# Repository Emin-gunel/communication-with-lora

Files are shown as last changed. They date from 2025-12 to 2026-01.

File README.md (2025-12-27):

# LoRa-Pico-BME280

Kısa açıklama  
Raspberry Pi Pico 2 W ve Ai-Thinker RA-01 (SX1278) kullanılarak, BME280 sensöründen alınan sıcaklık/nispi nem/basınç verilerinin LoRa P2P ile diğer bir Pico node'a gönderilip terminalde gösterilmesi amaçlanmıştır. Dengeli, sade ve doğrudan kullanılabilir bir proje yapısı sunar.

---

## İçindekiler
- [Açıklama](#açıklama)  
- [Özellikler](#özellikler)  
- [Donanım](#donanım)  
- [Yazılım Mimarisi](#yazılım-mimarisi)  
- [Haberleşme Parametreleri](#haberleşme-parametreleri)   
- [Çalıştırma / Seri Monitör](#çalıştırma--seri-monitör)  
- [Testler](#testler)  
- [Katkıda Bulunma](#katkıda-bulunma)  
- [İletişim](#iletişim)

---

## Açıklama
Bu proje iki Pico tabanlı node (verici ve alıcı) arasında LoRa P2P haberleşmesi ile sensör verisi aktarımı gerçekleştirir. Verici tarafında BME280 sensöründen okunup paketlenen veriler LoRa ile gönderilir; alıcı tarafı bu paketleri alıp seri (terminal) üzerinde gösterir.

## Özellikler
- Basit P2P LoRa iletişimi (verici ↔ alıcı)  
- BME280 ile sıcaklık, nem ve basınç okuma  
- Taşınabilir C++ tabanlı uygulama (Pico SDK ile C/C++)
  
## Donanım
- Raspberry Pi Pico 2 W (her iki node için)  
- BME280 sensörü (I2C) — verici tarafta  
- AI Thinker RA-01 (SX1278) LoRa modülü — her node için ayrı modül  
- Anten (uygun 433 MHz anten)  
- Güç kaynağı (USB güç)

## Yazılım Mimarisi
- Sensör okuma (BME280, I2C)  
- Veri paketleme (koşullu, küçük paket yapısı)  
- LoRa gönderim (SX1278 üzerinden SPI)  
- RX tarafında alma ve seri terminale yazma

C++ standardı: C++17 (proje C++ ile yazılmıştır).

## Haberleşme Parametreleri
- Frekans: 433 MHz  
- Spreading Factor: SF7  
- Bandwidth: 125 kHz  
- Coding Rate: 4/5  
- TX Gücü: 17 dBm

Bu parametreler LoRa link'i ve menzili doğrudan etkiler — gerekirse ayarlanabilir.

## Çalıştırma / Seri Monitör
- Seri hız: 115200 baud (varsayılan; proje içinde değiştirilebilir).  
- Terminal ile izleme örneği:

```bash
# Linux / macOS
picocom /dev/ttyUSB0 -b 115200
# veya
minicom -D /dev/ttyUSB0 -b 115200
```
Verici: sensör verilerini periyodik olarak paket gönderir.  
Alıcı: gelen paketları çözümler ve terminale yazdırır.

## Testler
- Projede otomatik test altyapısı yoksa, ilk testler manuel olacaktır: verici ve alıcıyı aynı ortamda çalıştırıp, sensör okuma ve paket alımını doğrulayın.  
- Bir sonraki adım: basit bir loopback testi ve menzil testi yapmaktır (farklı mesafeler/engeller altında paket kaybını kontrol edin).

## Katkıda Bulunma
1. Fork → branch oluştur (ör. feature/iyileme-adi)  
2. Değişiklik yap → test et → PR aç  
3. Küçük, odaklı PR'lar tercih edilir; büyük değişiklikler için önce issue açın.

## İletişim
- Sahip / Repo: https://github.com/Emin-gunel (güncellemek isterseniz gerçek repo linkinizi ekleyin)

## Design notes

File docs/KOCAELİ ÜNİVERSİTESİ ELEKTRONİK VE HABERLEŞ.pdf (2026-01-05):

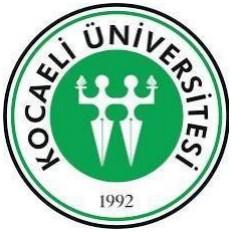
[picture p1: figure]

RASPBERRY Pİ PİCO 2W TABANLI LORA NOKTADAN NOKTAYA SENSÖR VERİ AKTARIMI SİSTEMİ

MÜHENDİSLİK TASARIM-1 DÖNEM PROJESİ Muhammet Emin GÜNEL 220208004

KOCAELİ ÜNİVERSİTESİ MÜHENDİSLİK FAKÜLTESİ Bölümü: Elektronik ve Haberleşme Mühendisliği Danışman: DOÇ. DR. ANIL ÇELEBİ

KOCAELİ, 2025

İÇİNDEKİLER

6.PROJEDE KULLANILAN YAZILIMLAR VE PROJE

### 1. GİRİŞ

Bu projede, Raspberry Pi Pico 2 W ve Ai-Thinker RA-01 LoRa modülleri kullanılarak iki nokta arasında kablosuz veri aktarımı gerşekleştirilmesi hedeflenmektedir. Verici tarafta BME280 sıcaklık–nem–basınç sensöründen alınan veriler LoRa P2P protokolü ile alıcı node’a aktarılmakta, alıcı bu veriyi terminalde göstermektedir. 2. PROJENİN AMACI

- Düşük güç tüketimli, uzun menzilli kablosuz haberleşme sistemi tasarlamak. ● LoRa P2P (Peer-to-Peer) haberleşmesini uygulamak. ● Sensör verisini güvenli şekilde iki cihaz arasında iletmek.

3.SİSTEM MİMARİSİ
3.1.Donanım Bileşenleri
- Raspberry Pi Pico 2W
- BME280 Sensörü
- AI Thinker RA-01(SX1278)
- Anten
- Güç Beslemesi

Sistem, bir verici (TX) ve bir alıcı (RX) düğümden oluşmaktadır. Verici düğümde BME280 sensörü kullanılarak çevresel veriler ölçülmüş, bu veriler mikrodenetleyici tarafından işlenerek LoRa modülü üzerinden kablosuz olarak iletilmiştir.

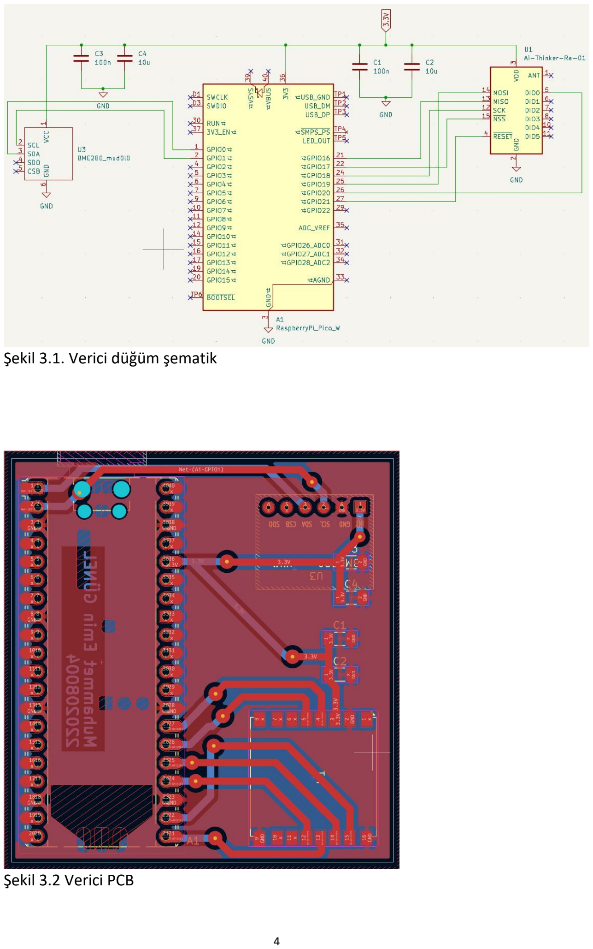
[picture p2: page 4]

Şekil 3.1. Verici düğüm şematik

Şekil 3.2 Verici PCB

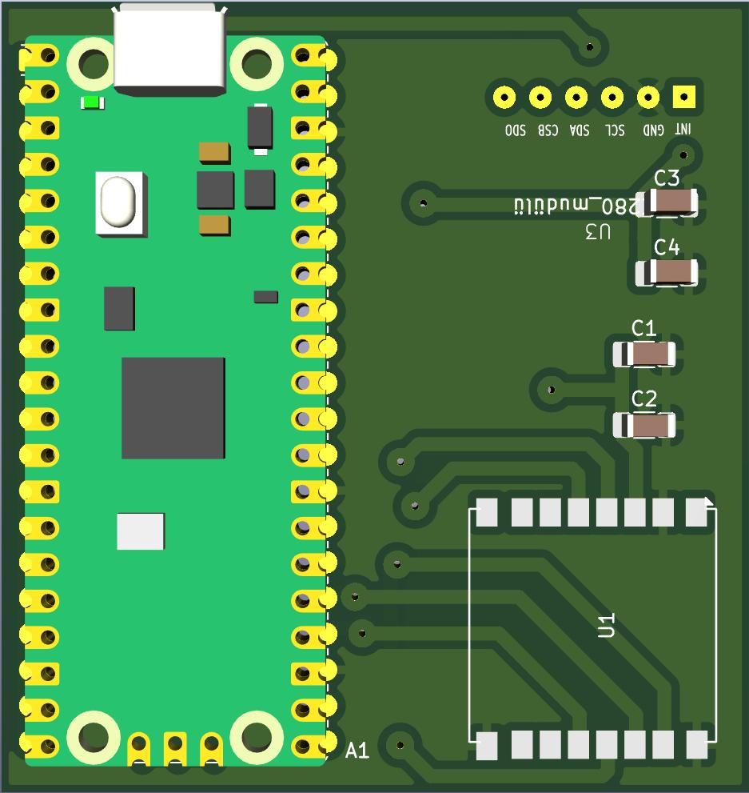
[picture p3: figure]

Şekil 3.3 Verici 3D görsel

3.2.Yazılım Mimarisi
- Sensör okuma
- Veri paketleme
- LoRa gönderim
- RX tarafında alma ve gösterme

Yazılım yapısı modüler olarak tasarlanmıştır. Sensör okuma, veri paketleme ve LoRa haberleşme işlemleri ayrı fonksiyonlar halinde gerçekleştirilmiştir.

3.3.Sistem Blok Diyagramı

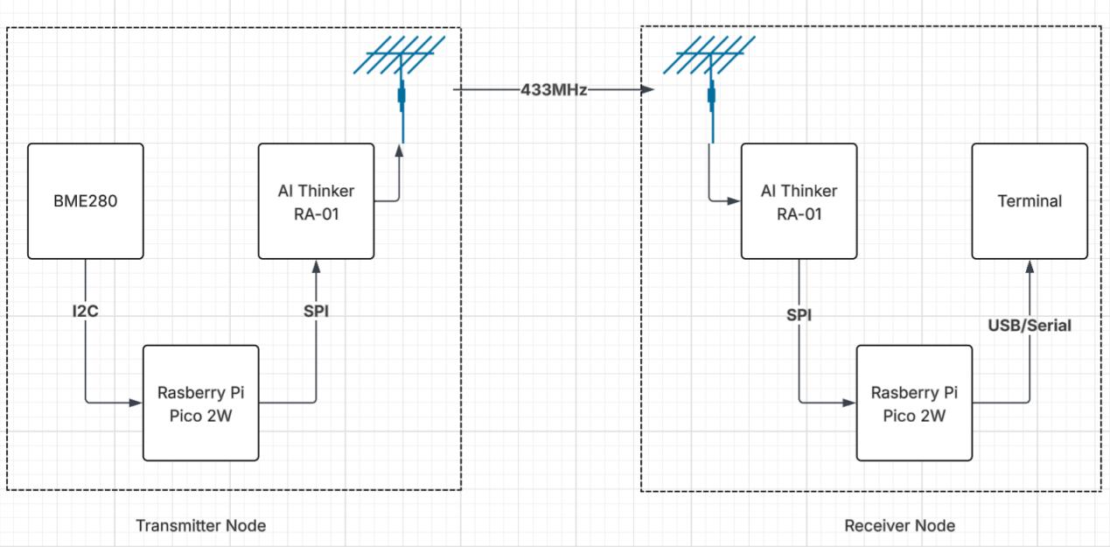
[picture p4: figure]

Şekil 3.4.Blok diyagram

### 3. TEST PROSEDÜRLERİ

### 3.1. Donanım Test Prosedürleri

Test kodu | Açıklama | Beklenen | Pass/Fail
Hw1 | PCB’de basılan yolların kısa devre testi | Yolun gelmesi. iki ucu arasına multimetrenin kısa devre modunda iken tutulduğunda bip sesi | Pass
Hw2 | GND ve VCC arasında kısa devre testi | GND ve VCC arasına multimetre tutulduğunda bip sesi gelmemesi.. kısa devre modunda iken | Pass
Hw3 | GND ve yollar arasında kısa devre testi | VCC ve yollar arsında multimetre kısa devre modunda ilken gezdirildiğinde bip sesi gelmem | Pass
Hw4 | GND ve yollar arasında kısa devre testi | GND gelmemesi. ve yollar arasında multimetre kısa devre modunda iken tutulduğunda bip sesi | Pass

### 3.2. Yazılım Test Prosedürleri

Test kodu | Açıklama | Beklenen | Pass/Fail
L1 | Sanity (BME280 + LoRa Init) | Sensör ve RA-01 çalışması doğrulama | Pass
L2 | PST Testi (100 paket) | Gönderilen ve alınan paket sayısının birbirine eşit olması. | Pass
L3 | Sensör Testi (30 paket) | Sıcaklık, görülmesi beklenir. nem ve basınç değerlerinin alıcı tarafta eksiksiz | Pass
L4 | Soak (20 dk) | RSSI ve SNR değerleri ilk ve son olmaması beklenir. paket arasında farklılıkların büyük | Pass

### 4. HABERLEŞME YAPISI VE PARAMETRELER

Frekans | 433MHz
Spedind factor | SF7
Bandwidth | 125kHz
Coding rate | 4/5
TX güç | 17dBm

LoRa haberleşmesi P2P modunda gerçekleştirilmiş olup, sistem parametreleri kısa mesafede düşük gecikme ve kararlı iletişim sağlayacak şekilde ayarlanmıştır. 5. MALİYET ANALİZİ

2x Raspberry pi pico 2w | 2x383.53 TL
2x AI Thinker RA-01 | 2x438.60 TL
4x Kapasitör | 4x10 TL
1x BME280 sensör | 236.50 TL

6.PROJEDE KULLANILAN YAZILIMLAR VE PROJE DOKÜMANLARI

6.1.Verici Düğüm’de Koşan Kodlar

firmware/Verici_kod.v · main · EminGnl-Kocaeli Univercity / MuhTas1-220208004- (https://gitlab.com/emingnl-kocaeli-univercity/emingnl-communucation-with-lora/-/blob/main/firmware/Verici_kod.v) MuhammetEminGÜNEL · GitLab (https://gitlab.com/emingnl-kocaeli-univercity/emingnl-communucation-with-lora/-/blob/main/firmware/Verici_kod.v)

6.2.Alıcı Düğüm’de Koşan Kodlar

firmware/Alıcı_kod.v · main · EminGnl-Kocaeli Univercity / MuhTas1-220208004- (https://gitlab.com/emingnl-kocaeli-univercity/emingnl-communucation-with-lora/-/blob/main/firmware/Al%C4%B1c%C4%B1_kod.v) MuhammetEminGÜNEL · GitLab (https://gitlab.com/emingnl-kocaeli-univercity/emingnl-communucation-with-lora/-/blob/main/firmware/Al%C4%B1c%C4%B1_kod.v)

6.3.Proje Dökümanları Ve GitLab Deposu

EminGnl-Kocaeli Univercity / MuhTas1-220208004- (https://gitlab.com/emingnl-kocaeli-univercity/emingnl-communucation-with-lora) MuhammetEminGÜNEL · GitLab (https://gitlab.com/emingnl-kocaeli-univercity/emingnl-communucation-with-lora)

### 6. SONUÇ

Bu çalışmada, LoRa tabanlı bir sensör veri iletim sistemi başarıyla gerçekleştirilmiştir. Yapılan testler sonucunda sistemin kısa mesafede kararlı ve güvenilir şekilde çalıştığı gösterilmiştir.

### 7. KAYNAKÇA

[1] https://pip.raspberrypi.com/documents/RP-008304-DS-1-pico-2- w-datasheet.pdf
[2] http://pdf.direnc.net/upload/bme280-i2c-basinc-sicaklik-ve-nem- sensoru-datasheet.pdf
[3] https://pdf.direnc.net/upload/ra-01-antenli-lora-modulu- datasheet.pdf

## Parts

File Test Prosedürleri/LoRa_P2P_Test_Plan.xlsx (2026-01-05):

LoRa P2P TEST PLAN
Test Kodu | Açıklama | Beklenen | Pass/Fail
L1 | Sanity (BME280 + LoRa Init) | İki init OK | Pass
L2 | CNT Testi (100 paket) | PER ≤ %2 | Pass
L3 | Sensör Testi (30 paket) | T/H/P mantıklı aralık | Pass
L4 | İç Mekân 30m | PER ≤ %5 | Pass
L5 | Soak (20 dk) | PER ≤ %2 | Pass

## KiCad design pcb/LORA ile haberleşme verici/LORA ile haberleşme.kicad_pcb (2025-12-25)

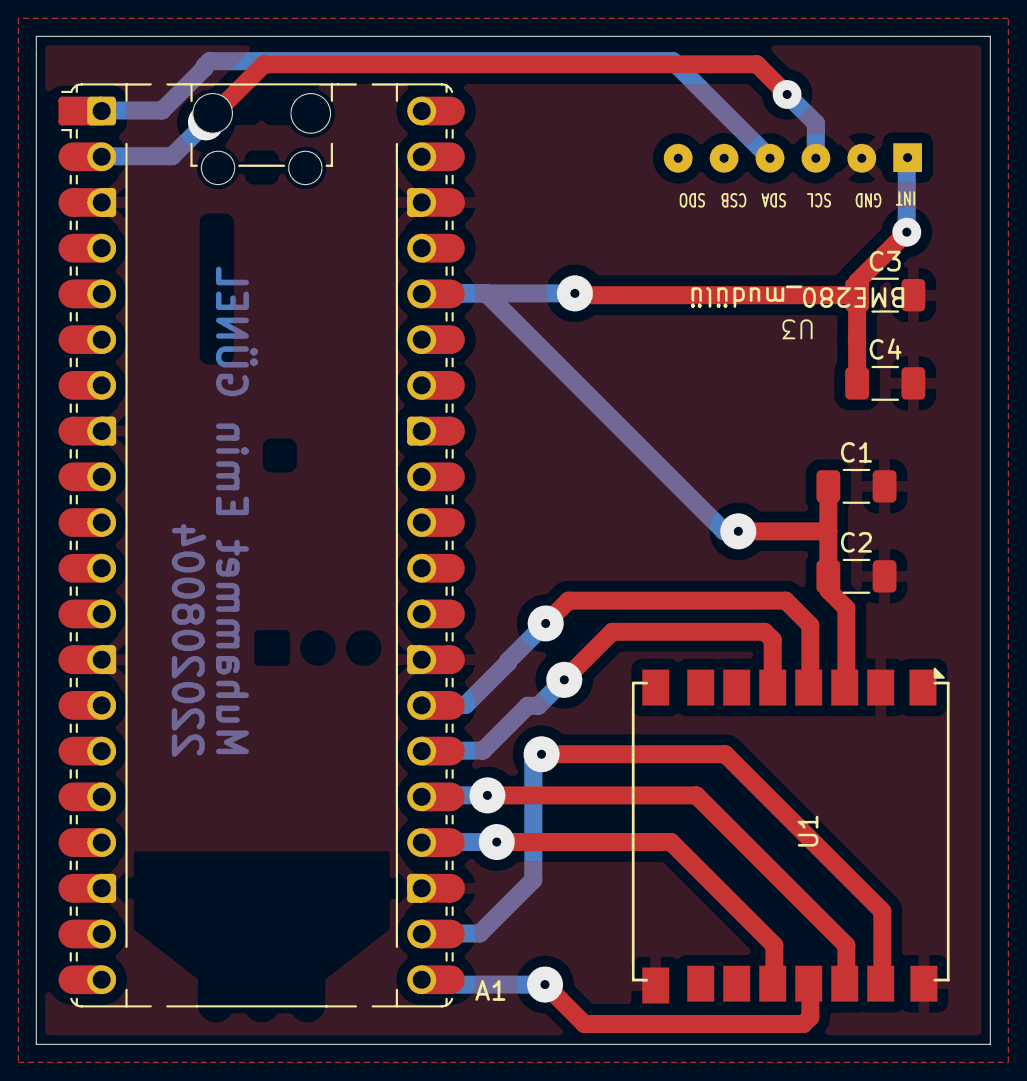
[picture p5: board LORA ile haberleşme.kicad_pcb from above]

Board: 4 copper layers, 53.0 x 56.0 mm, 7 parts (0 on the bottom side), 10 nets.

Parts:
A1: RaspberryPi_Pico_W; RaspberryPi_Pico_Common_Unspecified
C1, C3: 100n; C_1206_3216Metric_Pad1.33x1.80mm_HandSolder
C2, C4: 10u; C_1206_3216Metric_Pad1.33x1.80mm_HandSolder
U1: Ai-Thinker-Ra-01; Ai-Thinker-Ra-01-LoRa
U3: BME280_mudülü; Untitled

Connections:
3.3V: A1.36 (3V3), C1.1, C2.1, C3.1, C4.1, U1.3 (VDD), U3.1 (VCC)
GND: A1.3 (GND), A1.8 (GND), A1.13 (GND), A1.18 (GND), A1.23 (GND), A1.28 (GND), A1.38 (GND), C1.2, C2.2, C3.2, C4.2, U1.2 (GND), U1.9 (GND), U1.16 (GND), U3.6 (GND)
unnamed: A1.1 (GPIO0), U3.3 (SDA)
unnamed: A1.2 (GPIO1), U3.2 (SCL)
unnamed: A1.21 (GPIO16), U1.13 (MISO)
unnamed: A1.22 (GPIO17), U1.15 (~NSS)
unnamed: A1.24 (GPIO18), U1.12 (SCK)
unnamed: A1.25 (GPIO19), U1.14 (MOSI)
unnamed: A1.26 (GPIO20), U1.5 (DIO0)
unnamed: A1.27 (GPIO21), U1.4 (~RESET)

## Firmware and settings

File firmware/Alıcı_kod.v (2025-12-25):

#include <SPI.h>
#include <RadioLib.h>

// -------- LoRa PINLER --------
#define LORA_CS    17
#define LORA_DIO0  20
#define LORA_RST   21

// -------- SPI PINLER --------
#define SPI_SCK   18
#define SPI_MISO  16
#define SPI_MOSI  19

SX1278* lora;

void setup() {
  Serial.begin(115200);
  while (!Serial) { delay(10); }
  Serial.println("=== RX KART ===");

  // ---- SPI baslat ----
  SPI.setSCK(SPI_SCK);
  SPI.setRX(SPI_MISO);
  SPI.setTX(SPI_MOSI);
  SPI.begin();
  Serial.println("SPI OK");

  // ---- SX1278 ----
  lora = new SX1278(new Module(LORA_CS, LORA_DIO0, LORA_RST));

  int state = lora->begin(433.0);
  if (state != RADIOLIB_ERR_NONE) {
    Serial.print("LoRa init HATA, kod = ");
    Serial.println(state);
    while (1);
  }

  // ---- TX ile AYNI parametreler ----
  lora->setSpreadingFactor(7);
  lora->setBandwidth(125.0);
  lora->setCodingRate(5);

  Serial.println("RX modunda, paket bekleniyor...");
}

void loop() {
  String incoming;

  int state = lora->receive(incoming);

  if (state == RADIOLIB_ERR_NONE) {
    Serial.print("ALINDI: ");
    Serial.println(incoming);

    Serial.print("RSSI: ");
    Serial.print(lora->getRSSI());
    Serial.print(" dBm | SNR: ");
    Serial.print(lora->getSNR());
    Serial.println(" dB");
    Serial.println("------------------------");
  }
}

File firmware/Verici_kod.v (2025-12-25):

#include <SPI.h>
#include <Wire.h>
#include <RadioLib.h>
#include <Adafruit_BME280.h>

// -------- LoRa PINLER --------
#define LORA_CS    17
#define LORA_DIO0  20
#define LORA_RST   21

#define SPI_SCK   18
#define SPI_MISO  16
#define SPI_MOSI  19

// -------- BME280 PINLER --------
#define SDA_PIN 0
#define SCL_PIN 1

SX1278* lora;
Adafruit_BME280 bme;

int packetCounter = 0;

void setup() {
  Serial.begin(115200);
  while (!Serial) { delay(10); }
  Serial.println("BME280 + LoRa TX basladi");

  // ---- I2C (BME280) ----
  Wire.setSDA(SDA_PIN);
  Wire.setSCL(SCL_PIN);
  Wire.begin();

  if (!bme.begin(0x76)) {
    Serial.println("BME280 bulunamadi!");
    while (1);
  }
  Serial.println("BME280 OK");

  // ---- SPI (LoRa) ----
  SPI.setSCK(SPI_SCK);
  SPI.setRX(SPI_MISO);
  SPI.setTX(SPI_MOSI);
  SPI.begin();

  lora = new SX1278(new Module(LORA_CS, LORA_DIO0, LORA_RST));

  if (lora->begin(433.0) != RADIOLIB_ERR_NONE) {
    Serial.println("LoRa init hatasi!");
    while (1);
  }

  lora->setSpreadingFactor(7);
  lora->setBandwidth(125.0);
  lora->setCodingRate(5);
  lora->setOutputPower(17);

  Serial.println("LoRa TX hazir");
}

void loop() {
  // ---- SENSOR OKUMA ----
  float temperature = bme.readTemperature();
  float humidity    = bme.readHumidity();
  float pressure    = bme.readPressure() / 100.0;

  // ---- VERI PAKETLEME ----
  String packet =
    "ID:" + String(packetCounter) +
    ";T:" + String(temperature, 1) +
    ";H:" + String(humidity, 1) +
    ";P:" + String(pressure, 1);

  // ---- LoRa GONDER ----
  int state = lora->transmit(packet);

  if (state == RADIOLIB_ERR_NONE) {
    Serial.print("GONDERILDI: ");
    Serial.println(packet);
  } else {
    Serial.println("TX HATASI");
  }

  packetCounter++;
  delay(2000);
}

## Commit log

2025-12-25 Add PCB, firmware, report and README
    [LORA ile Haberleşme alıcı.kicad_pcb, LORA ile Haberleşme alıcı.kicad_sch, LORA ile haberleşme.kicad_pcb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]
2025-12-27 Update README.md — LoRa-Pico-BME280
2025-12-27 Update README.md — content revisions
2026-01-05 Test Prosedürleri yüklendi
    [LoRa_P2P_Test_Log.xlsx, LoRa_P2P_Test_Plan.xlsx]
2026-01-05 Test prosedürleri güncellendi
    [LoRa_P2P_Test_Log.xlsx, LoRa_P2P_Test_Plan.xlsx]
